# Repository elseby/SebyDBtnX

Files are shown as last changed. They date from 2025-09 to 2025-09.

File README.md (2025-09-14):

# SebyDBtnX – Open Source Home Automation Device

**SebyDBtnX** is an open-source home automation project designed to integrate seamlessly with the **Bticino MyHome** system.  
It enables control of actuators such as **lights**, **roller shutters**, and **CEN commands** directly on the bus.

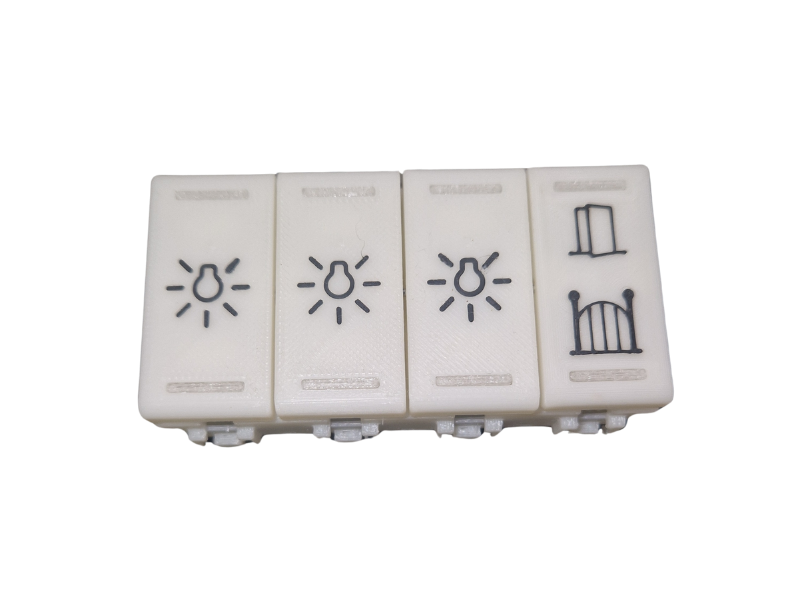
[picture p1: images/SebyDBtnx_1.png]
SebyDBtnX Device Image

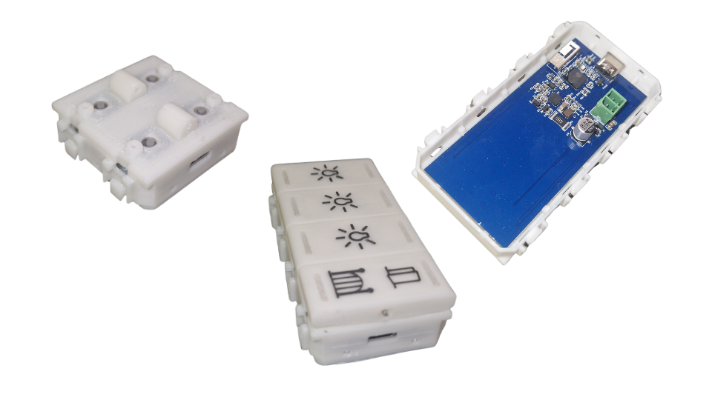
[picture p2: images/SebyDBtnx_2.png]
SebyDBtnX Device Image


## ✨ Features
- Control actuators on the Bticino MyHome bus  
- Up to **10 commands per button**  
- Button LED indicates the status of the first command  
- Configurable LED color combinations  
- No external software required for setup  
- Web-based configuration via internal Wi-Fi server  
- **Websocket channel** to monitor bus frame traffic  
- OTA firmware updates supported  
- Currently there are pcb and stl with 8 buttons (4 modules) and 4 buttons (2 modules) available
---

## ⚙️ Hardware Overview
- **MCU:** ESP32-S3FH4R2 SoC  
  - 4MB Flash  
  - Integrated Wi-Fi for setup and OTA updates  
  - Peripherals: UART, IRDA, RMT, etc.  
- **Bus Interface:** STKNX chip  
  - Handles bus communication  
  - Provides onboard switching power supply  
- Compact PCB designed for easy integration  

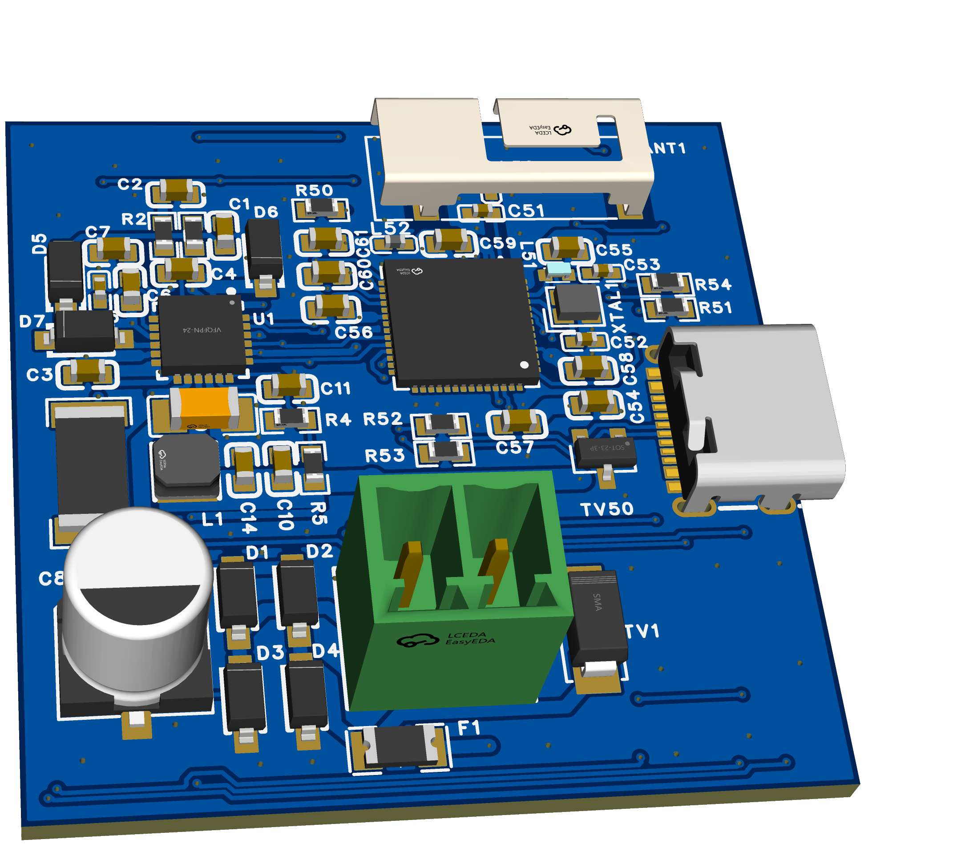
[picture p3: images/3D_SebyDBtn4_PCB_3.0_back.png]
PCB Image

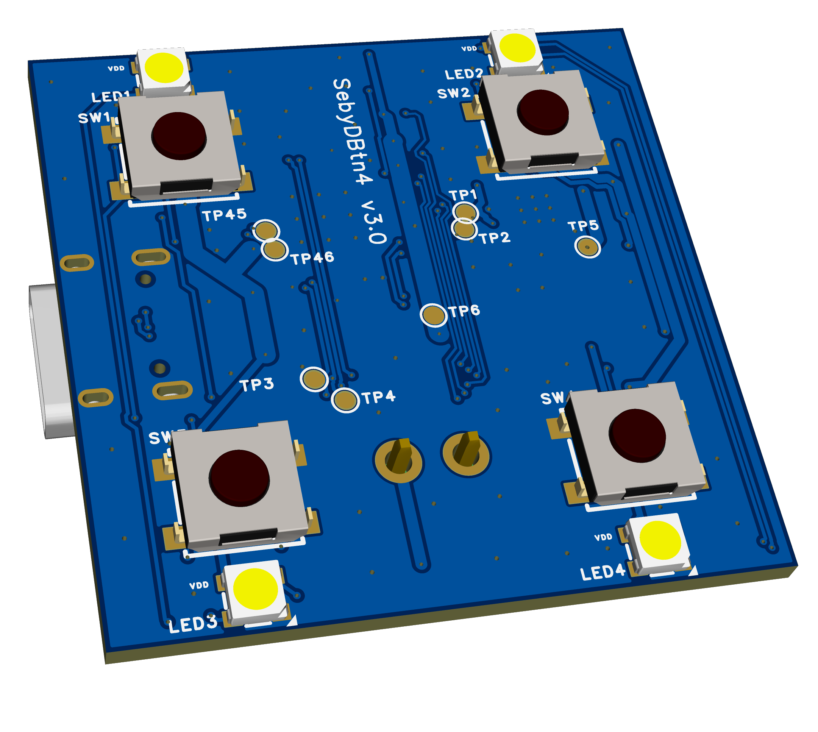
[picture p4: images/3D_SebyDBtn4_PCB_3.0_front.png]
PCB Image


---

## 🛠️ Setup & Configuration

## Setup WEB Page
to enable wifi AP press left/up and right/down button for 3 seconds.
After connected to wifi AP the setup page is available at local address http://192.168.4.1. The websocket is available at address: ws://192.168.4.1/ws

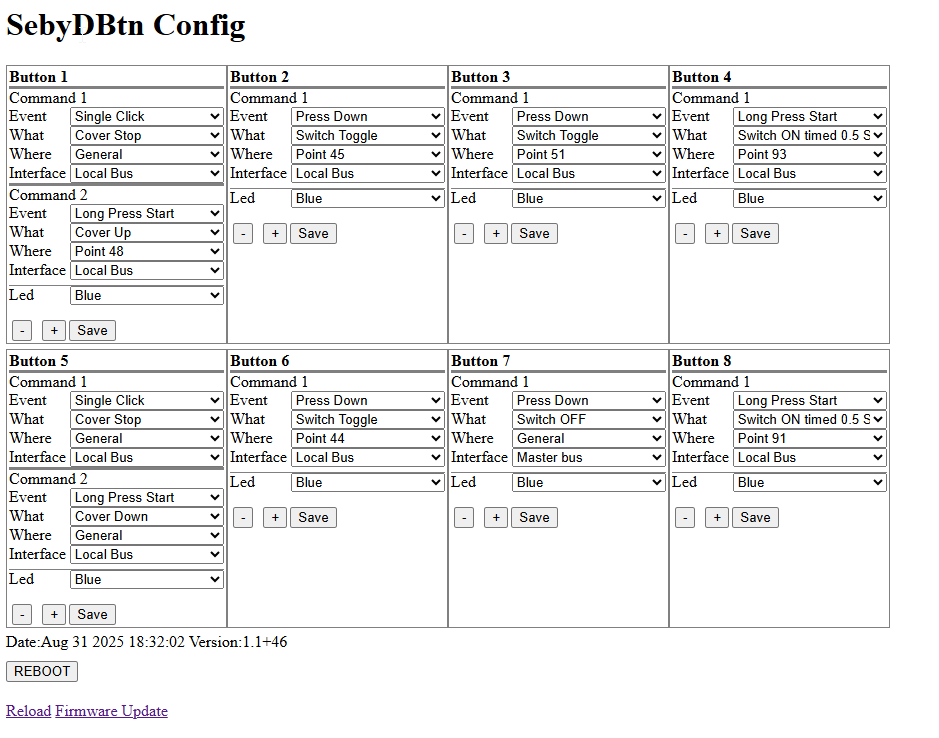
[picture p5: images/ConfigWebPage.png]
Setup Web Page


You must edit the config.h file before compiling by commenting/uncommenting the line with the correct pattern

---

## 🔗 Communication
- **Web page**: Full configuration and command setup  
- **Websocket channel**: Live monitoring of bus traffic  

---

## 📥 Firmware
- Latest firmware releases available under firmware folder  
- Flash via **OTA update** or **USB (UART)**

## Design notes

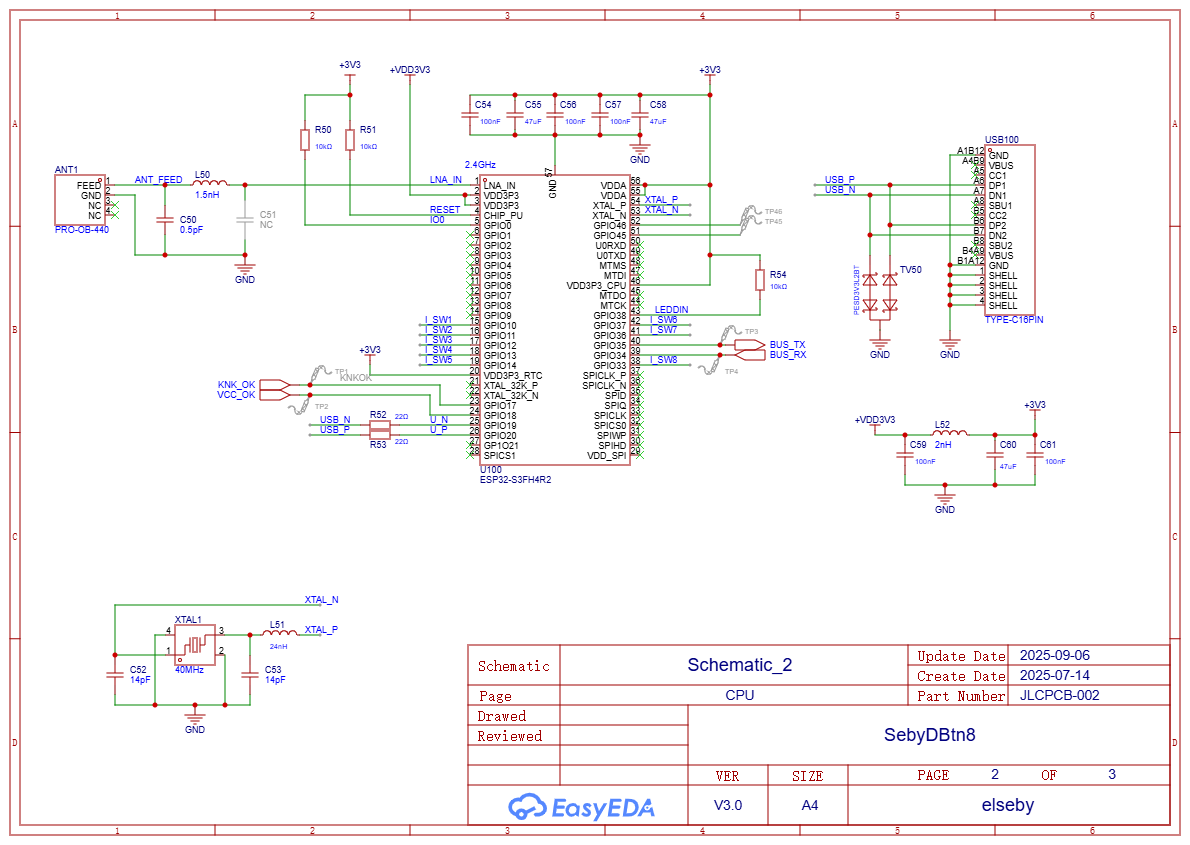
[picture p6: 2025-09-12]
hardware/SebyDBtn8/pcb/3.0/schematic/SCH_Schematic_2_2-CPU_2025-09-06.png

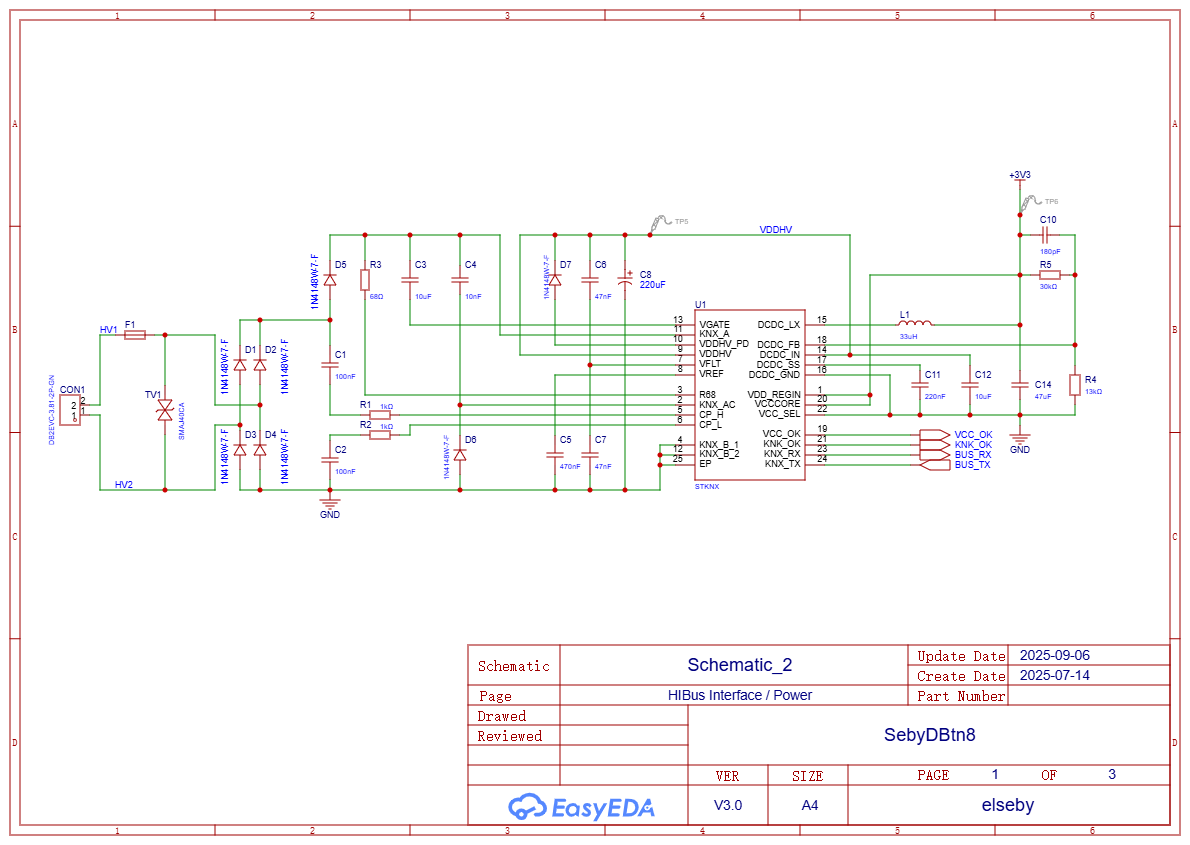
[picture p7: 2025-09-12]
hardware/SebyDBtn8/pcb/3.0/schematic/SCH_Schematic_2_1-HIBus Interface - Power_2025-09-06.png

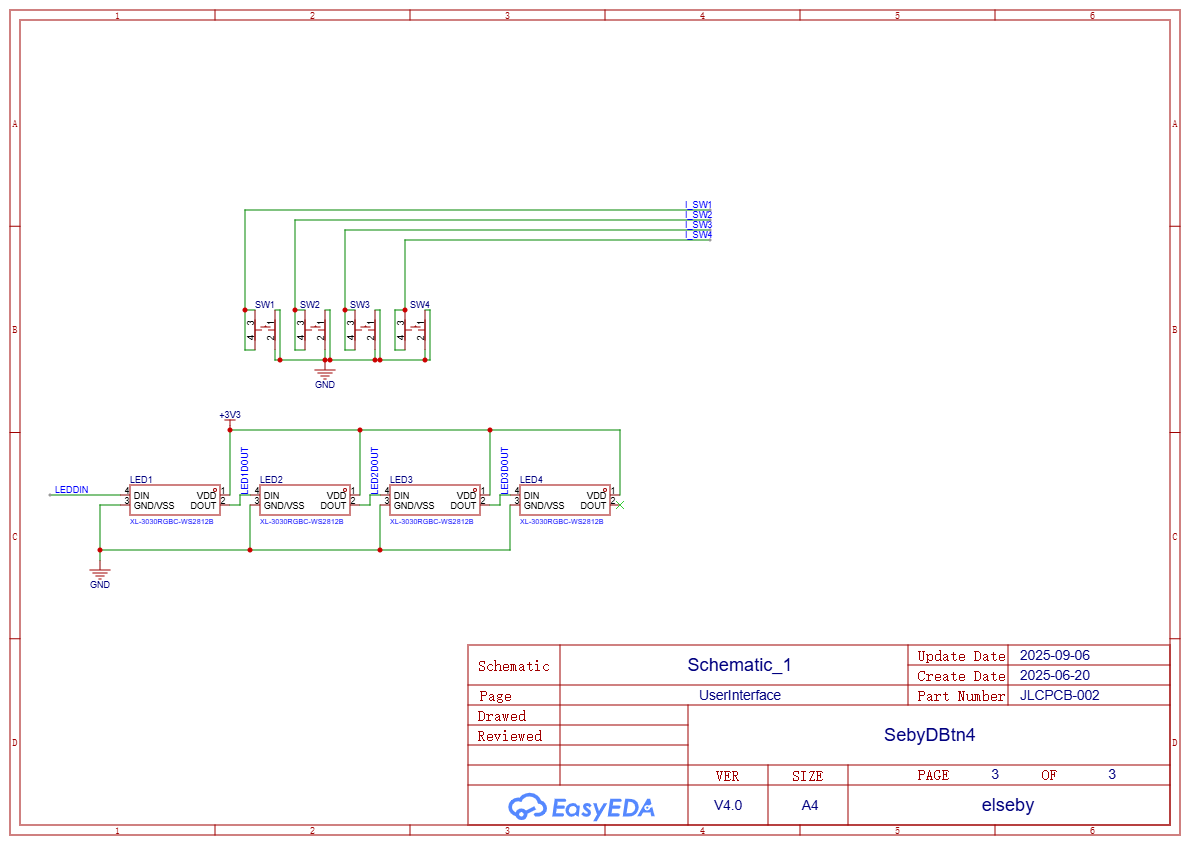
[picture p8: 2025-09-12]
hardware/SebyDBtn4/pcb/4.0/PNG_Schematic_1_2025-09-06/SCH_Schematic_1_3-UserInterface_2025-09-06.png

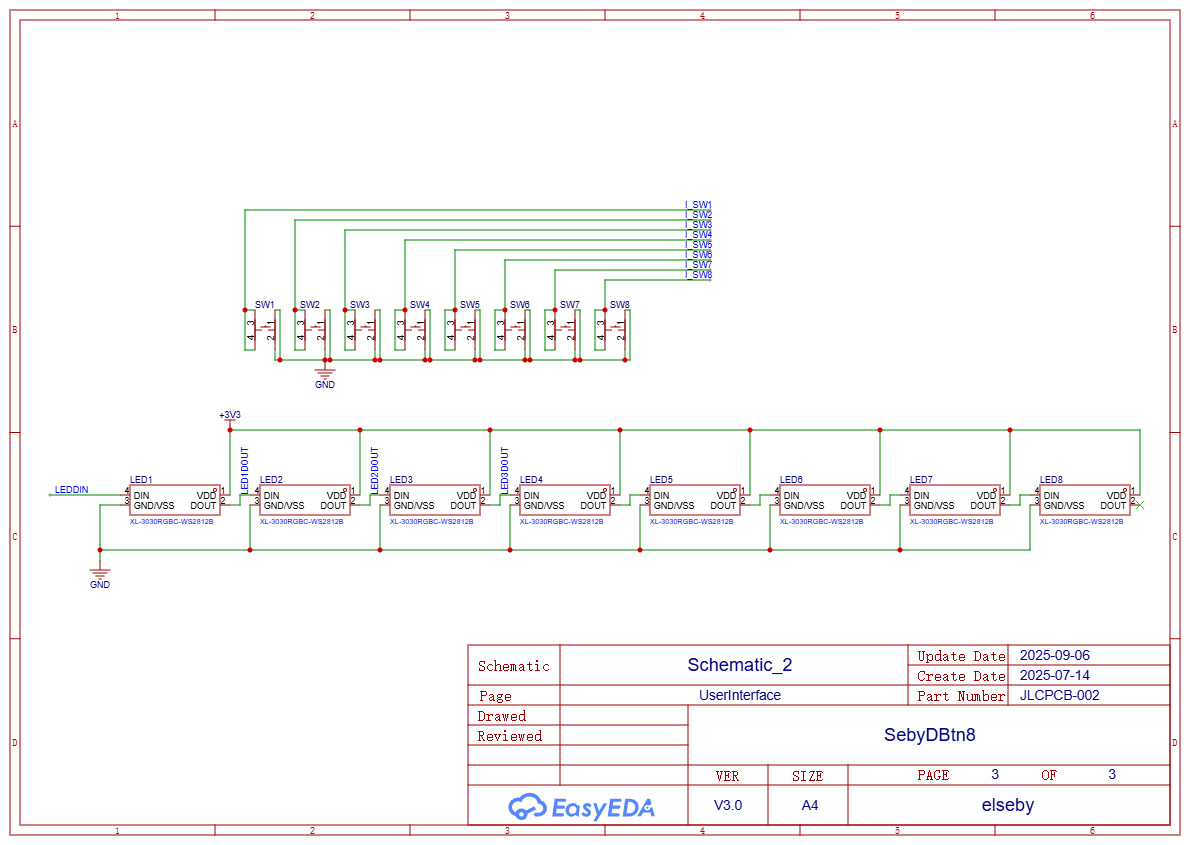
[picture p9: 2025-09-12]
hardware/SebyDBtn8/pcb/3.0/schematic/SCH_Schematic_2_3-UserInterface_2025-09-06.png

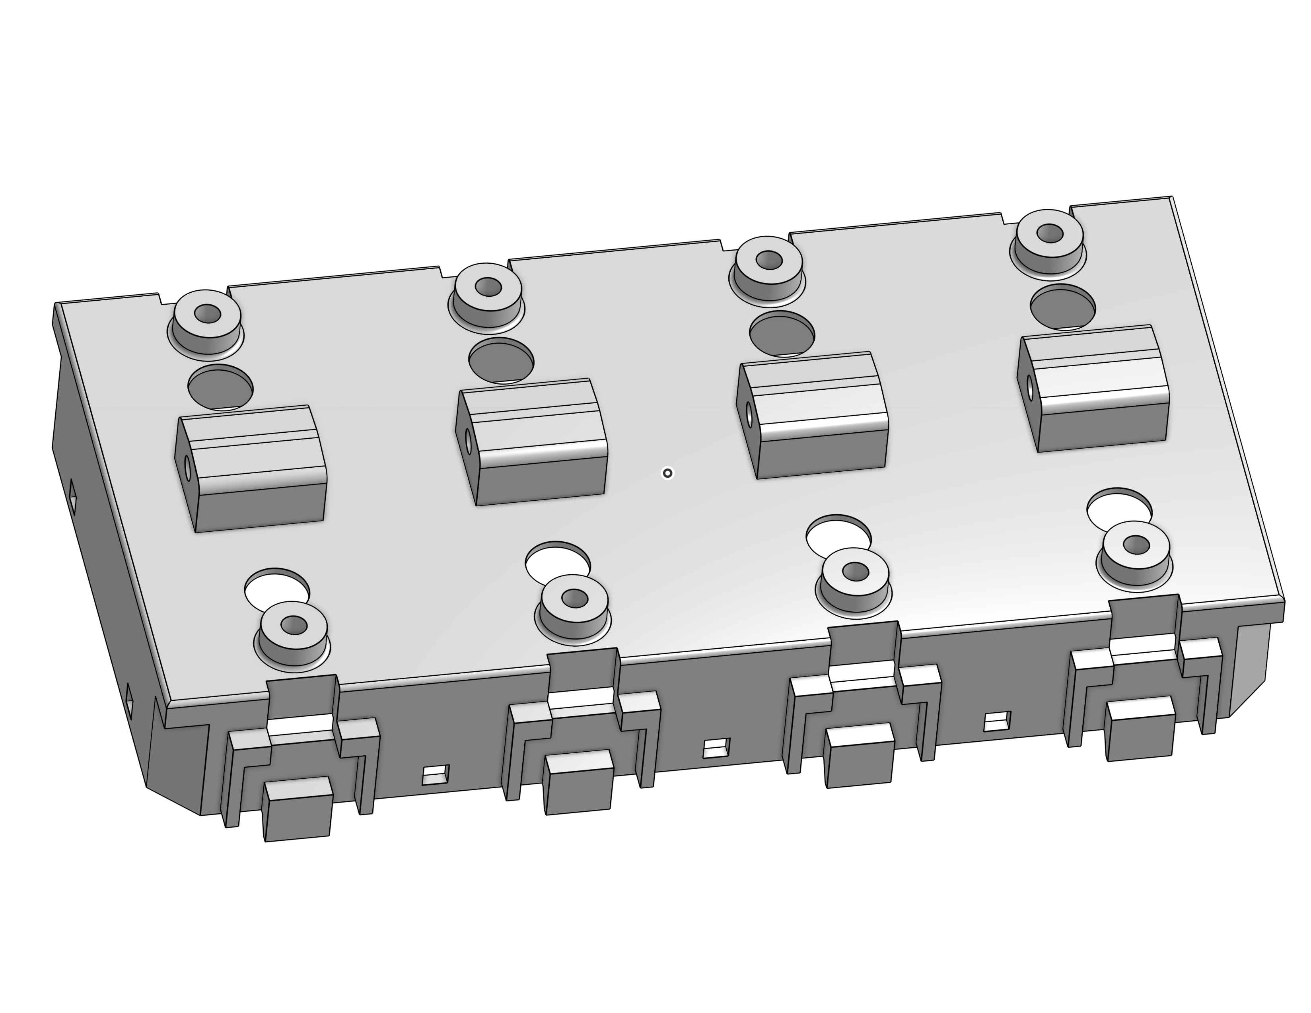
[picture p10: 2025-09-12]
images/SebyDBtn8_MainBody_V3.0.png

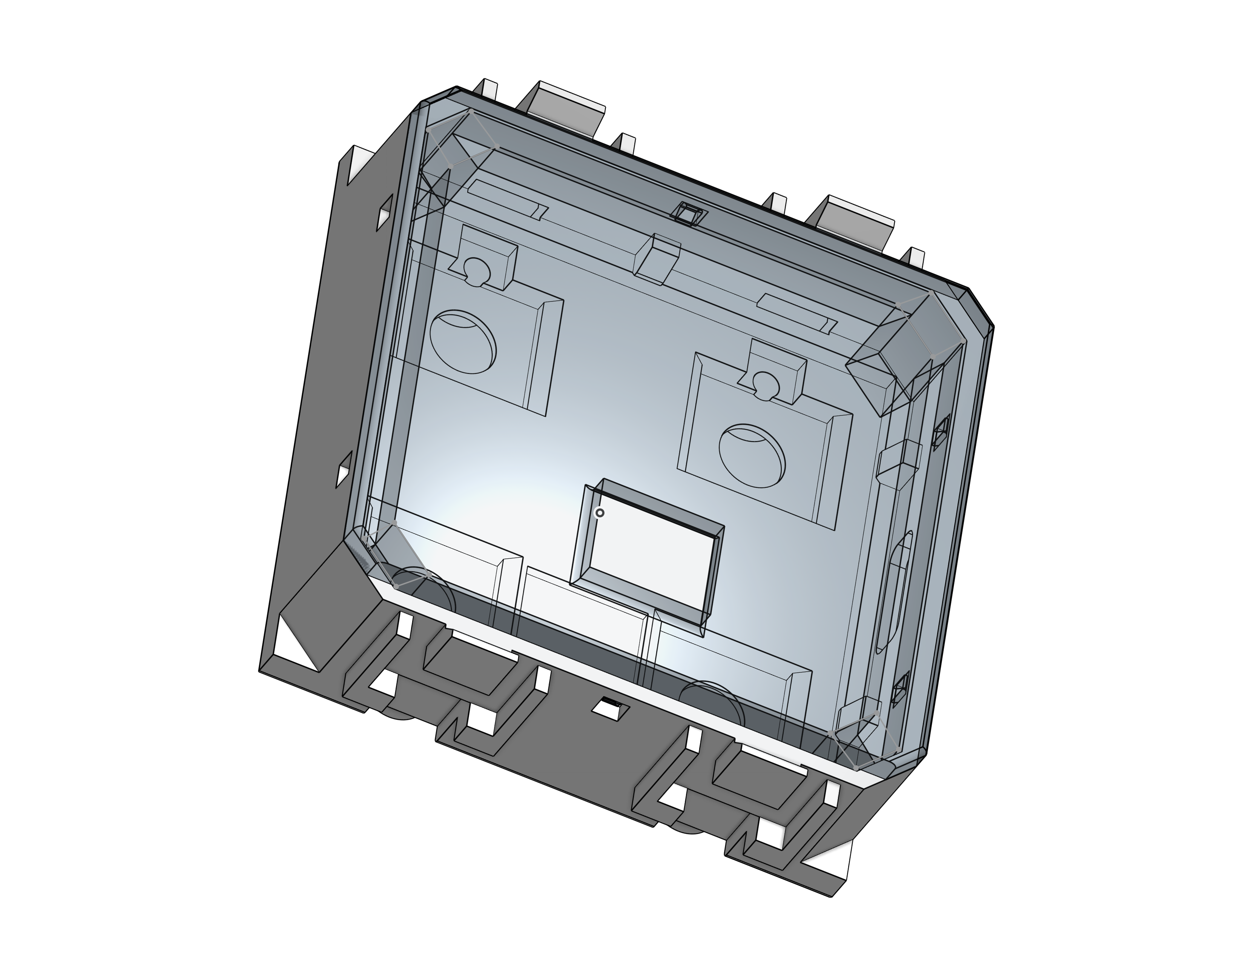
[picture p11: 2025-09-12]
images/SebyDBtn4_coverback.png

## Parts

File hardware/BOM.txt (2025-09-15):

-Mounted PCB (4 or 8 buttons)
	you can made by yourself using gerber and bom files into "pcb" directory
-Printed parts
	you can print by yourself using stl files, you need:
	-Front and Back cover ex: SebyDBtn8_MainBody_V3.0.stl (x1) + SebyDBtn8_BackCover_V3.0.stl (x1)
	-printed button with 2 light guides for each button
		(for example SebyDBtnx_Key_Light_1pos_V3.0.stl (x4) and SebyDBtnx_LightGuide_1pos_V3.0.stl (x8)
-2 springs for each button
	6mm diameter and 5mm height (0.3 / 0.5mm wire diameter)
	( https://it.aliexpress.com/item/1005001408294215.html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 )
-1.5mm diameter stainless steel rods (to be cut to the right size)

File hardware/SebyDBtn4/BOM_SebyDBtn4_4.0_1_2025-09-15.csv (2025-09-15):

No. | Quantity | Comment | Designator | Footprint | Value | Manufacturer Part | Manufacturer | LCSC Part Name
1 | 1 | 0.5pF | C50 | C0402 | 0.5pF | GJM1555C1HR50WB01D | muRata(村田) | ±0.05pF 0.5pF 50V
2 | 1 | 1.5nH | L50 | L0402 | 1.5nH | LQG15HS1N5S02D | muRata(村田) | 1.5nH ±0.3nH
3 | 1 | 2nH | L52 | L0402 | 2nH | LQG15HS2N0S02D | muRata(村田) | 2nH
4 | 1 | 2.4GHz | U100 | QFN-56_L7.0-W7.0-P0.40-BL-EP5.7 | 2.4GHz | ESP32-S3FH4R2 | ESPRESSIF(乐鑫) | ESP32-S3FH4R2
5 | 1 | 10nF | C4 | C0603 | 10nF | CC0603KRX7R0BB103 | YAGEO(国巨) | 10nF ±10% 100V
6 | 1 | 10uF | C3 | C0603 | 10uF | CL10A106KP8NNNC | SAMSUNG(三星) | 10uF ±10% 10V
7 | 1 | 10uF | C12 | C1206 | 10uF | GMK316AB7106KL-TR | TAIYO YUDEN(太诱) | 10uF ±10% 35V MSASG31LAB7106KTNB25
8 | 1 | 13kΩ | R4 | R0603 | 13kΩ | FRC0603F1302TS | FOJAN(富捷) | 13kΩ ±1% 100mW 厚膜电阻
9 | 1 | 24nH | L51 | IND-SMD_L1.2-W0.6 | 24nH | SCW1005C24NJST | Sunltech(韩国顺磁) | 24nH ±5%
10 | 1 | 30kΩ | R5 | R0603 | 30kΩ | RC0603FR-0730KL | YAGEO(国巨) | 厚膜电阻 30kΩ ±1% 100mW
11 | 1 | 33uH | L1 | IND-SMD_L3.0-W3.0_YHNR3012 | 33uH | YHNR3015-330M | YJYCOIN(益嘉源) | 33uH ±20% 900mA
12 | 1 | 40MHz | XTAL1 | CRYSTAL-SMD_4P-L2.0-W1.6-BL | 40MHz | TAXM40M4ZHBCDT2T | YJX(雅晶鑫) | 40MHz ±10ppm 15pF
13 | 1 | 68Ω | R3 | R2512 | 68Ω | 25121WJ0680T4E | UNI-ROYAL(厚声) | 68Ω ±5% 1W 厚膜电阻
14 | 1 | 180pF | C10 | C0603 | 180pF | CC0603JRNPO9BN181 | YAGEO(国巨) | 180pF ±5% 50V
15 | 1 | 220nF | C11 | C0603 | 220nF | CL10B224KB8NNNC | SAMSUNG(三星) | 220nF ±10% 50V
16 | 1 | 220uF | C8 | CAP-SMD_BD6.3-L6.6-W6.6-FD | 220uF | 189RV0019 | KNSCHA(科尼盛) | 220uF ±20% 35V
17 | 1 | 0466.500NRHF | F1 | F1206 |  | 0466.500NRHF | Littelfuse(美国力特) | 63V贴片式保险丝
18 | 1 | 470nF | C5 | C0402 | 470nF | GRM155R61H474KE11D | muRata(村田) | 470nF ±10% 50V
19 | 1 | DB2EVC-3.81-2P-GN | CON1 | CONN-TH_2P-P3.81_DB2EVC-3.81-2P-BK |  | DB2EVC-3.81-2P-GN | DORABO(地博电气) | 3.81mm 1x2P 排数:1 每排P数:2
20 | 1 | PESD3V3L2BT | TV50 | SOT-23-3_L2.9-W1.3-P1.90-LS2.4-BR |  | PESD3V3L2BT | TECH PUBLIC(台舟) | PESD3V3L2BT
21 | 1 | PRO-OB-440 | ANT1 | SEBY_ANT-SMD_5P-L13.8-W5.2_PRO-OB-440 |  | PRO-OB-440 | ABRACON | PRO-OB-440
22 | 1 | SMAJ40CA | TV1 | SMA_L4.3-W2.6-LS5.0-BI |  | SMAJ40CA | 宏嘉诚 | SMAJ40CA
23 | 1 | STKNX | U1 | VFQFPN-24_L4.0-W4.0-P0.50-BL-EP2.8 |  | STKNX | ST(意法半导体) | STKNX
24 | 1 | TYPE-C16PIN | USB100 | USB-C-SMD_TYPE-C16PIN |  | TYPE-C16PIN | SHOU HAN(首韩) | Type-C 母 卧贴
25 | 2 | 1kΩ | R1,R2 | R0603 | 1kΩ | 0603WAF1001T5E | UNI-ROYAL(厚声) | 1kΩ ±1% 100mW 厚膜电阻
26 | 2 | 14pF | C52,C53 | C0402 | 14pF | 0402CG140J500NT | FH(风华) | 14pF ±5% 50V
27 | 2 | 22Ω | R52,R53 | R0603 | 22Ω | RC0603FR-0722RL | YAGEO(国巨) | 厚膜电阻 22Ω ±1% 100mW
28 | 2 | 47nF | C6,C7 | C0603 | 47nF | TCC0603X7R473M500CT | CCTC(三环) | 47nF ±20% 50V
29 | 3 | 10kΩ | R50,R51,R54 | R0603 | 10kΩ | 0603WAF1002T5E | UNI-ROYAL(厚声) | 厚膜电阻 10kΩ ±1% 100mW
30 | 4 | 47uF | C14,C55,C58,C60 | C0603 | 47uF | GRM188R60J476ME15D | muRata(村田) | 47uF ±20% 6.3V
31 | 4 | GT-TC063E-H035-L30 | SW1,SW2,SW3,SW4 | SW-SMD_4P-L6.2-W6.2-P4.00-LS7.2 |  | GT-TC063E-H035-L30 | G-Switch(品赞) | 6.2*6.2*3.5mm 立贴 轻触开关
32 | 4 | XL-3030RGBC-WS2812B | LED1,LED2,LED3,LED4 | LED-SMD_4P-L3.0-W3.0-P2.00-LS3.1_YKL-3030AY0203Z-001 |  | XL-3030RGBC-WS2812B | XINGLIGHT(成兴光) | 幻彩透明
33 | 7 | 1N4148W-7-F | D1,D2,D3,D4,D5,D6,D7 | SOD-123_L2.7-W1.6-LS3.7-RD-1 |  | 1N4148W-7-F | DIODES(美台) | 电压:100V 电流:300mA
34 | 7 | 100nF | C1,C2,C54,C56,C57,C59,C61 | C0603 | 100nF | CC0603KRX7R0BB104 | YAGEO(国巨) | 100nF ±10% 100V

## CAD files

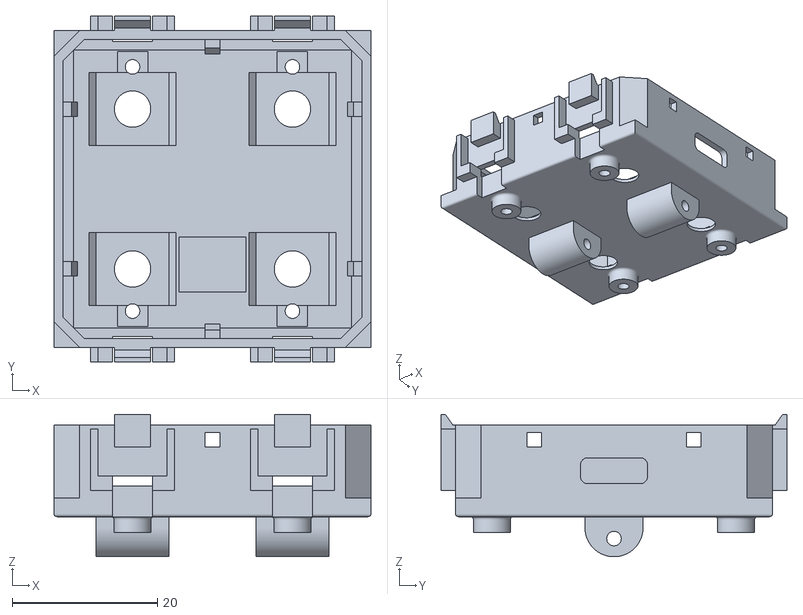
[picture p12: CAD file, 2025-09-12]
hardware/SebyDBtn4/stl/SebyDBtn4_MainBody_V3.0.stl
43.6 x 47.6 x 19.6

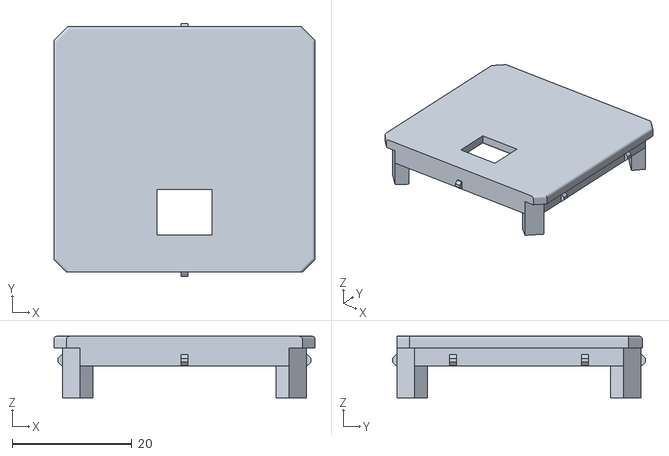
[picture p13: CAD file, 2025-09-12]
hardware/SebyDBtn4/stl/SebyDBtn4_BackCover_V3.0.stl
43.6 x 42.3 x 10.3

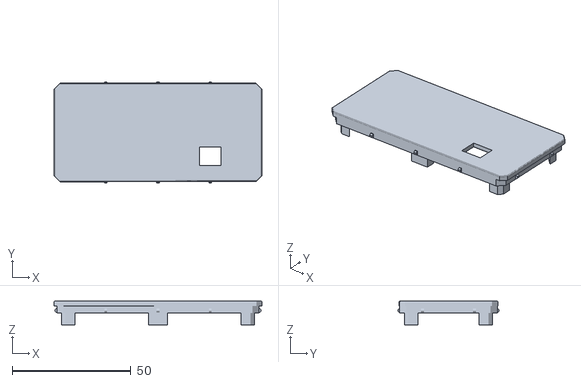
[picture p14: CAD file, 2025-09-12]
hardware/SebyDBtn8/stl/SebyDBtn8_BackCover_V3.0.stl
87.6 x 42.7 x 10.1

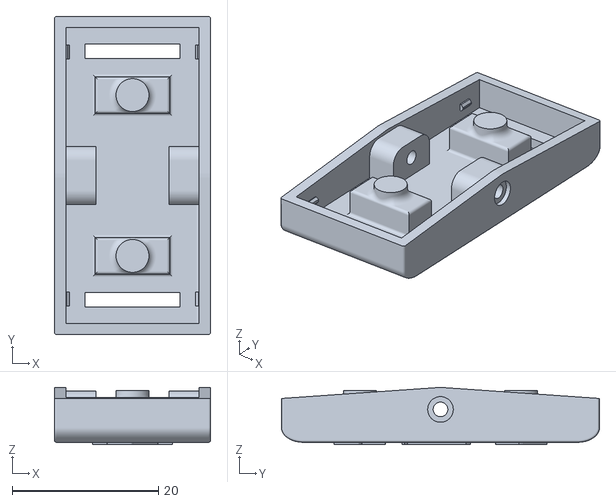
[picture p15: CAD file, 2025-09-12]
hardware/SebyDBtnX/stl/SebyDBtnx_Key_Cover_1pos_V3.0.stl
21.4 x 43.5 x 7.80

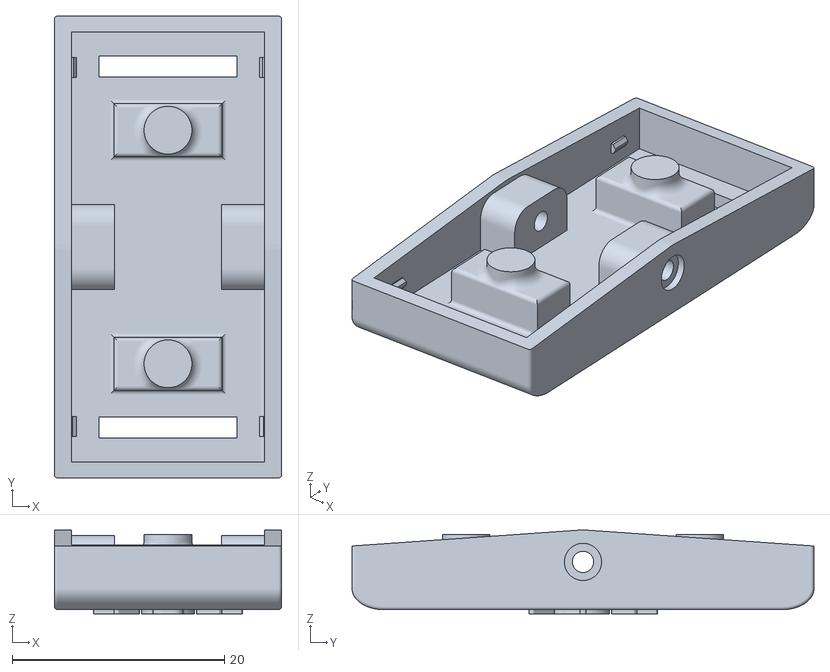
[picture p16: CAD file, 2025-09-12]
hardware/SebyDBtnX/stl/SebyDBtnx_Key_Light_1pos_V3.0.stl
21.4 x 43.5 x 7.90

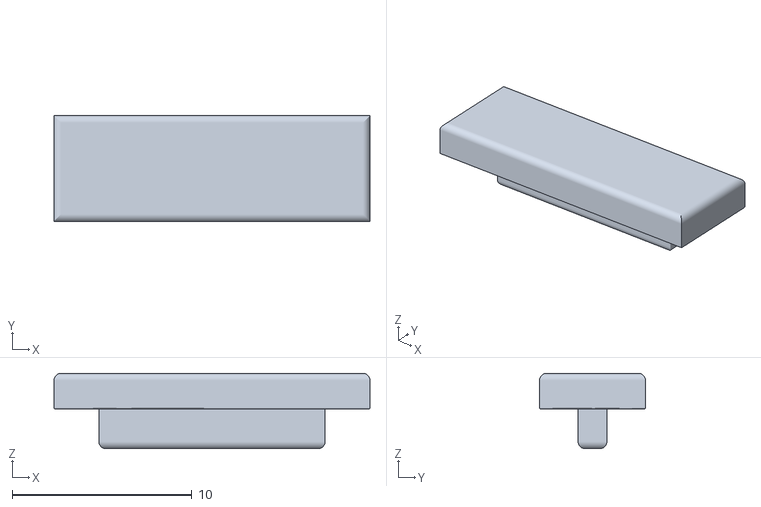
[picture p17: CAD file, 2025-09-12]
hardware/SebyDBtnX/stl/SebyDBtnx_LightGuide_1pos_V3.0.stl
17.6 x 5.90 x 4.20

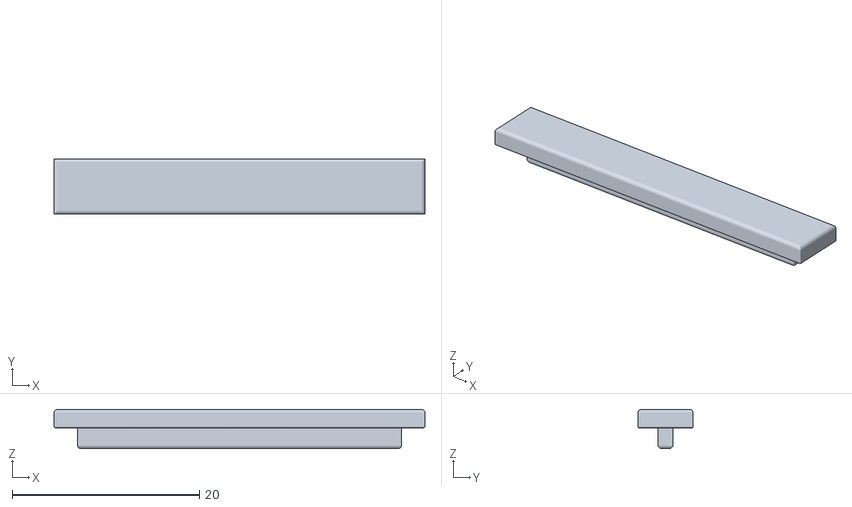
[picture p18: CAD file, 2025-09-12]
hardware/SebyDBtnX/stl/SebyDBtnx_LightGuide_2pos_V3.0.stl
39.6 x 5.90 x 4.20

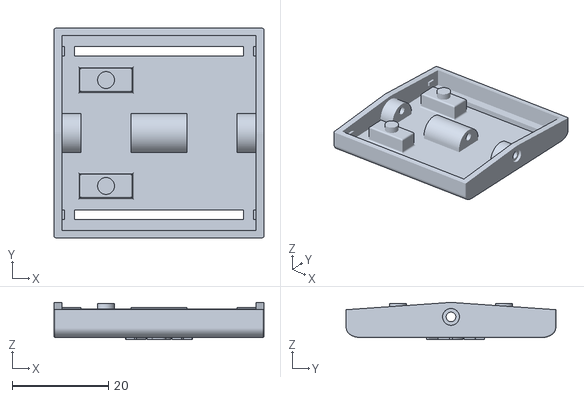
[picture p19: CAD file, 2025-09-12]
hardware/SebyDBtnX/stl/SebyDBtnx_Key_Light_2pos_V3.0.stl
43.6 x 43.5 x 7.70

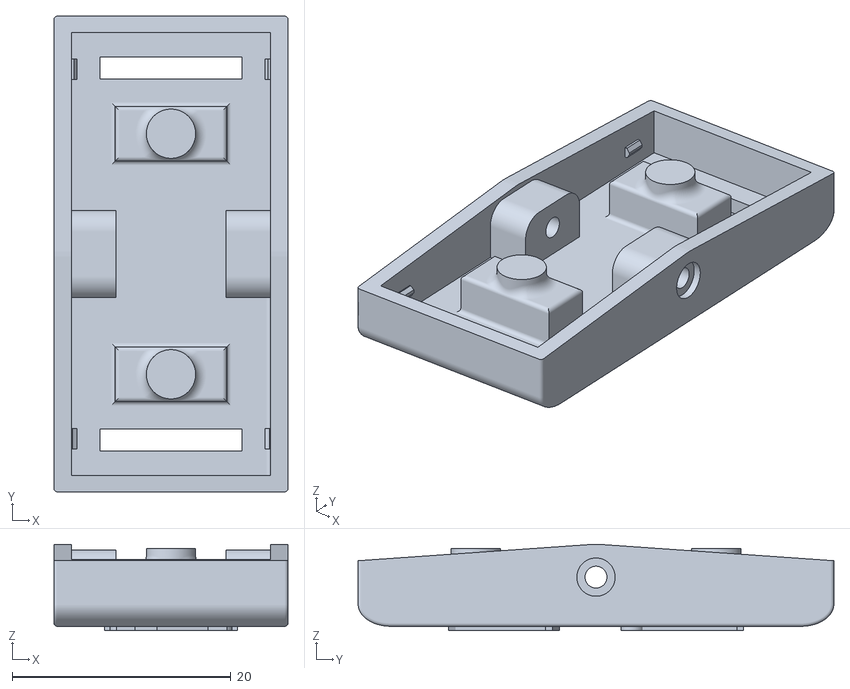
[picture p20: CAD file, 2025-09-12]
hardware/SebyDBtnX/stl/SebyDBtnx_Key_DoorGate_1pos_V3.0.stl
21.4 x 43.5 x 7.90

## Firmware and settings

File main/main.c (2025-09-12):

#include "driver/gpio.h"
#include "include/buttons.h"
#include "include/leds.h"
#include "include/busrtx.h"
#include "include/httpserver.h"
#include "freertos/idf_additions.h"
#include "nvs_flash.h"
#include <stdbool.h>
#include <stdio.h>
#include <sys/time.h>
#include <time.h>
#include <unistd.h>
#include "include/decoder.h"

void nvsInit(void);

void app_main(void) {

	nvsInit();
	
	ledsInit();

	initButtons();
	
	initApWebServer();	

	hibus_config_t busConfig = {
		.gpio_rx_port = GPIO_HIBUS_RX_PIN,
		.gpio_tx_port = GPIO_HIBUS_TX_PIN,
		.rx_handler = &rxDataDecoder
	};

	hibusInit(&busConfig);
	
	ledsInitSequence();

	printf("SebyD Ready!\n");

	setAllLed(LED_STATE_INACTIVE);
	
	#ifdef WIFIONATSTARTUP
	wifiToggle();
	#endif
	
	
	
	vTaskDelete(NULL);

}

void nvsInit(void){
	// Initialize NVS
	esp_err_t ret = nvs_flash_init();
	if (ret == ESP_ERR_NVS_NO_FREE_PAGES ||
		ret == ESP_ERR_NVS_NEW_VERSION_FOUND) {
		ESP_ERROR_CHECK(nvs_flash_erase());
		ret = nvs_flash_init();
	}
	ESP_ERROR_CHECK(ret);
}

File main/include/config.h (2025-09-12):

#pragma once
//************************************************************************************************/
// Select MODEL with number of buttons
//************************************************************************************************/
//#define DBTN1		// only for test (breadboard) 1 button
#define DBTN4		// SebyDBtn4 (2 module with 4 button)
//#define DBTN4_TEST	// SebyDBtn4 only for test 4 button and TP (test points)
//#define DBTN6		// SebyDBtn6 (3 module with 6 button)
//#define DBTN8		// SebyDBtn8 (4 module with 4 button)
//#define DBTN8_OLD		// SebyDBtn8 (only for test first HW version)
//************************************************************************************************/

#ifdef DBTN4_TEST	
	#define DBTN4
	#define WIFIONATSTARTUP
	#define TESTPOINT_A GPIO_NUM_45
	#define TESTPOINT_B GPIO_NUM_46
#endif

#define GPIO_LEDSTRIP  GPIO_NUM_38

#ifdef DBTN1
	#define NUM_OF_BUTTONS 1
	#define GPIO_BUTTON_1  GPIO_NUM_6
	#define GPIO_HIBUS_TX_PIN  GPIO_NUM_2
	#define GPIO_HIBUS_RX_PIN  GPIO_NUM_1
	#define HIBUS_INVERT_RX
#elifdef DBTN4
	#define NUM_OF_BUTTONS 4
	#define GPIO_BUTTON_1  GPIO_NUM_10
	#define GPIO_BUTTON_2  GPIO_NUM_11
	#define GPIO_BUTTON_3  GPIO_NUM_12
	#define GPIO_BUTTON_4  GPIO_NUM_13
	#define GPIO_HIBUS_TX_PIN  GPIO_NUM_35
	#define GPIO_HIBUS_RX_PIN  GPIO_NUM_34
	#define HIBUS_INVERT_RX
#elifdef DBTN6
	#define NUM_OF_BUTTONS 6
	#define GPIO_BUTTON_1  GPIO_NUM_10
	#define GPIO_BUTTON_2  GPIO_NUM_11
	#define GPIO_BUTTON_3  GPIO_NUM_12
	#define GPIO_BUTTON_4  GPIO_NUM_13
	#define GPIO_BUTTON_5  GPIO_NUM_14
	#define GPIO_BUTTON_6  GPIO_NUM_37
	#define GPIO_HIBUS_TX_PIN  GPIO_NUM_35
	#define GPIO_HIBUS_RX_PIN  GPIO_NUM_34
	#define HIBUS_INVERT_RX
#endif

#ifndef DBTN8_OLD
	#define HIBUS_INVERT_RX
#endif
#ifdef DBTN8_OLD
	#define DBTN8
#endif

#ifdef DBTN8
	#define NUM_OF_BUTTONS 8
	#define GPIO_BUTTON_1  GPIO_NUM_10
	#define GPIO_BUTTON_2  GPIO_NUM_11
	#define GPIO_BUTTON_3  GPIO_NUM_12
	#define GPIO_BUTTON_4  GPIO_NUM_13
	#define GPIO_BUTTON_5  GPIO_NUM_14
	#define GPIO_BUTTON_6  GPIO_NUM_37
	#define GPIO_BUTTON_7  GPIO_NUM_36
	#define GPIO_BUTTON_8  GPIO_NUM_33
	#define GPIO_HIBUS_TX_PIN  GPIO_NUM_35
	#define GPIO_HIBUS_RX_PIN  GPIO_NUM_34
#endif

#define NUM_OF_LEDS NUM_OF_BUTTONS

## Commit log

2025-09-12 -Initial release
    [SebyDBtn4_BackCover_V3.0.stl, SebyDBtn4_MainBody_V3.0.stl, SebyDBtn8_BackCover_V3.0.stl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]
2025-09-15 -pcb and hardware bom added
    [BOM_SebyDBtn4_4.0_1_2025-09-15.csv, BOM_SebyDBtn8_v3.0_2025-09-15.csv]
